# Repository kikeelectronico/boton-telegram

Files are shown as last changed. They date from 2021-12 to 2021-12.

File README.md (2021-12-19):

# El botón de Telegram
Se trata de un botón que envia un mesaje a través de Telegram hasta a cuatro usuarios.

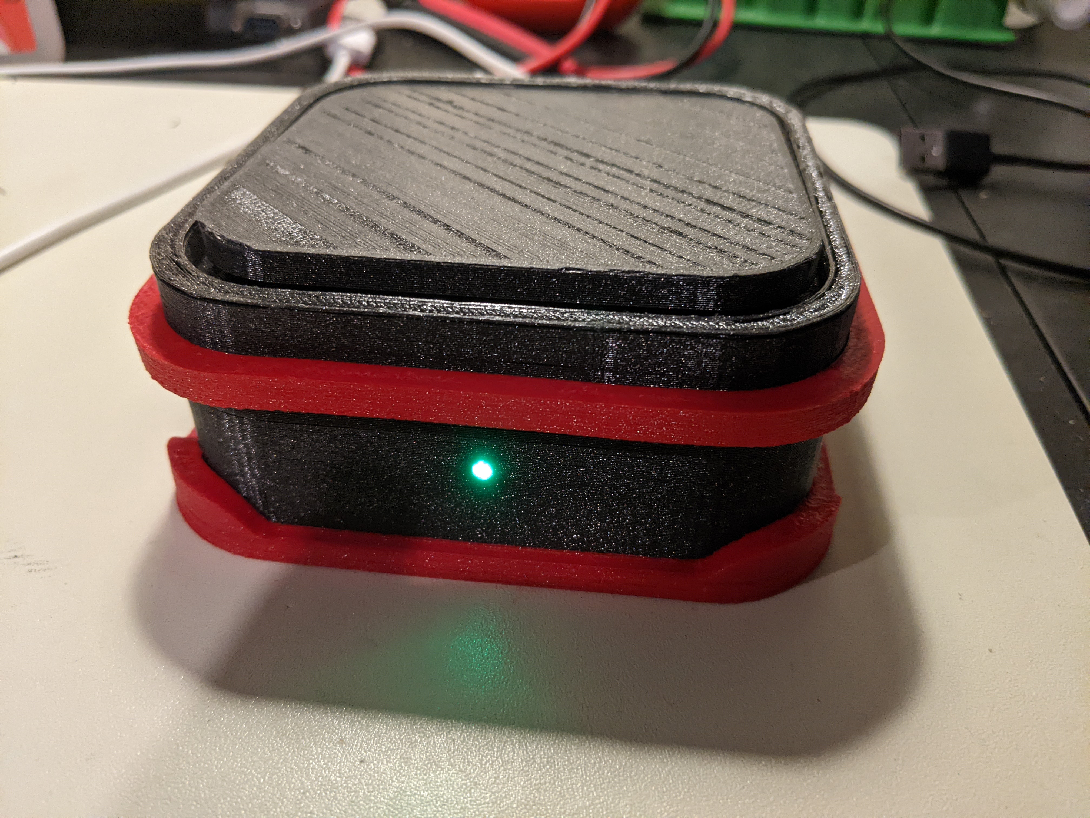
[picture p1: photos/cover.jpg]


# Materiales

- WeMos D1 mini
- Final de carrera.
- WS2812B LED
- PLA o material similar
- 2 tuercas M3
- 2 tornillos 45xM3
- Cable unifilar
- Tubo termoretráctil

# Herramientas

- PC
- Arduino IDE
- Soldador
- Impresora 3D

# Construcción

1. Imprime los modelos 3D de la caja.
2. Coloca el final de carrera usando los pines horizontales del centro de la pieza llamada Base.
3. Pega el LED detrás del agujero frontal de la base.
4. Coloca la placa WeMos D1 mini en el espacio reservado en el interior de la base.
5. Conecta el LED a Vcc, GND y al pin digital D6.
6. Conecta el final de carrera a GND y al pin digital D7.
7. Programa la placa usando el firmware y el IDE de Arduino.
8. Inserta 2 tuercas de métrica 3 en los huecos hexagonales de la pieza llamada Tapa.
9. Encaja la pieza llamada Botón en la pieza Tapa a través los agujeros redondos.
10. Encaja la Tapa en la Base y cierrala con dos tornillos de métrica 3 y 45 mm de largo desde la parte inferior.
11. Coloca las piezas decorativas: antideslizante y anillo.

# Conectar a tu red WiFi y configura el mensaje

Para realizar la configuración, El botón de Telegram genera su propia página web y red WiFi temporal a la que solo puedes acceder al estar cerca del dispositivo.

Para configurar botón:

1. Presiona el botón y no lo sueltes.
2. Conecta el cable USB.
3. Espera a que el LED se encienda en color amarillo.
4. Suelta el botón.

El botón de Telegram ha creado una red WiFi temporal llamada _Soy tu botón_ cuya contraseña es _vamosaconfigurarcosas_.

5. Conecta tu ordenador o dispositivo móvil a la red WiFi del botón.

Puede que el ordenador o el dispositivo móvil detecten que la red WiFi no tiene conexión a Internet. Si es así, el dispositivo pregunta si quieres mantener la conexión: mantenla.

6. Abre un navegador web y accede a la dirección http://192.168.4.1.
7. Rellena los datos de tu red WiFi, el token de tu bot de Telegram y el mensaje a enviar.

# Vincular una cuenta de Telegram para recibir mensajes

El botón puede enviar el mensaje hasta a cuatro usuarios de Telegram. Estos usuarios deben estar vinculados, un proceso que solo puedes llevar a cabo teniendo acceso físico al botón.

Para vincular un usuario:

1. Buscar tu bot en Telegram.
2. Inicia una conversación con el bot.
3. Envía el comando /start al bot y espera su respuesta.
4. Envía el comando /vincular y espera a que el LED del botón cambie al color morado.
5. Pulsa el botón.

Si el proceso de vinculación es correcto, el LED parpadea en color verde dos veces y el usuario recibe un mensaje del bot confirmando el proceso.

Si el proceso de vinculación falla, el LED parpadea en color rojo varias veces y el usuario recibe un mensaje del bot informando de que el proceso ha ido mal.

# El LED de colores

El botón de Telegram dispone de un LED con el que indica su estado.

|  Color |  Significado |
|---|---|
| Azul, fijo  | El dispositivo se está iniciando.  |
| Azul, parpadeo  | El dispositivo está buscando la red WiFi.  |
| Amarillo, fijo  | El dispositivo se encuentra en modo de configuración.  |
| Verde, parpadeo  | El proceso ha sido un éxito.  |
| Rojo, parpadeo  | El proceso ha fallado.  |
| Verde, fijo  | El dispositivo está preparado para enviar mensajes.  |

# Licencia
Creative Commons Atribución-CompartirIgual 4.0 Internacional.

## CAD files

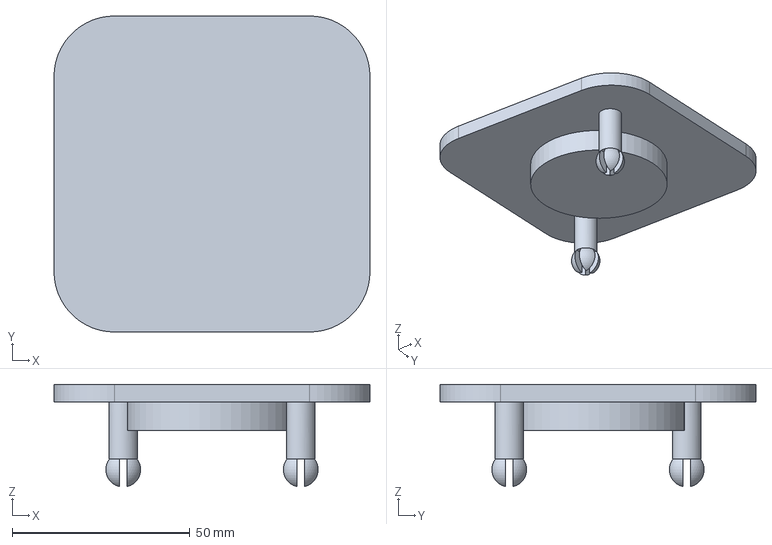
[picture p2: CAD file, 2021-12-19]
3D/botón.FCStd
89.0 x 89.0 x 28.8 mm

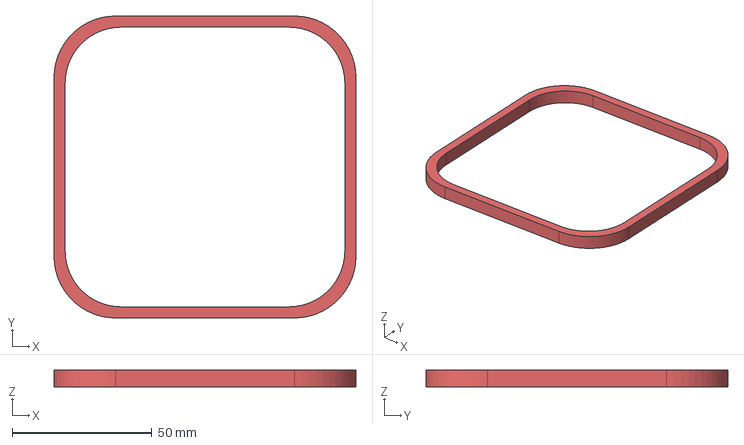
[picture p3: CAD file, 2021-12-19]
3D/anillo.FCStd
108.0 x 108.0 x 6.00 mm

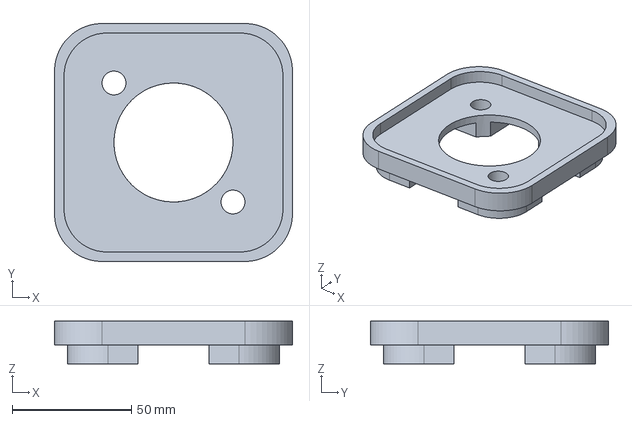
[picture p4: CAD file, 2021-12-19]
3D/tapa.FCStd
100.0 x 100.0 x 18.0 mm

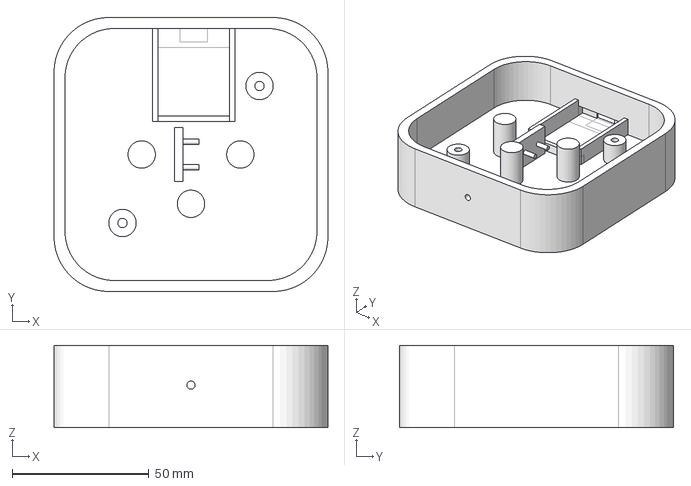
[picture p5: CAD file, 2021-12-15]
3D/base.FCStd
100.0 x 100.0 x 30.0 mm

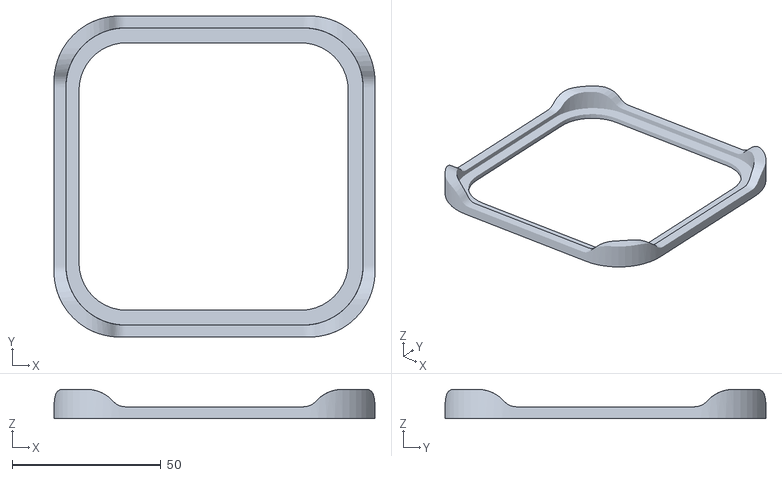
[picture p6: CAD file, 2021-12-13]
3D/antideslizante.stl
108.0 x 108.0 x 9.86

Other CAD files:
3D/anillo.stl
3D/base.stl
3D/botón.stl
3D/tapa.stl

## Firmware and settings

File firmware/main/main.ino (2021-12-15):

#include <ESP8266WiFi.h>
#include <EEPROM.h>
#include <WiFiClientSecure.h>
#include <UniversalTelegramBot.h>
#include <ESP8266WebServer.h>
#include <Adafruit_NeoPixel.h>
#include "constants.h"
#include "struct.h"
#include <stdio.h>
#include <string.h>

// Instances
X509List cert(TELEGRAM_CERTIFICATE_ROOT);
WiFiClientSecure client;
UniversalTelegramBot bot("", client);
Adafruit_NeoPixel pixels = Adafruit_NeoPixel(1, LED_PIN, NEO_GRB + NEO_KHZ800);
ESP8266WebServer server(80);

// Operational variables
configuration config;
volatile bool push_button_flag = false;
unsigned long start_wifi_time;
unsigned long start_link_time;
unsigned long last_bot_pool;
bool ap_mode = false;

ICACHE_RAM_ATTR void pushButtonInterrupt() {
  push_button_flag = true;
}

// Web server handlers
void handleRoot() {
  server.send(200, "text/html", SETTINGS_HOME_PAGE_1 + String(config.ssid)
                              + SETTINGS_HOME_PAGE_2 + String(config.password)
                              + SETTINGS_HOME_PAGE_3 + String(config.bot_token)
                              + SETTINGS_HOME_PAGE_4 + String(config.message)
                              + SETTINGS_HOME_PAGE_5);
}

void handleSave() {
  if (server.argName(0) == "ssid"
      && server.argName(1) == "password"
      && server.argName(2) == "bot_token"
      && server.argName(3) == "message") {
    // Save the settings
    server.arg(0).toCharArray(config.ssid, 50);
    server.arg(1).toCharArray(config.password, 50);
    server.arg(2).toCharArray(config.bot_token, 50);
    server.arg(3).toCharArray(config.message, 50);
    // Update the eeprom memory
    EEPROM.put(0,config);
    EEPROM.commit();
    server.send(200, "text/html", SETTINGS_SAVED_SUCCESS_1 + server.arg(0) + SETTINGS_SAVED_SUCCESS_2);
    for(uint8_t i = 0; i < 2; i++) {
      led(0,255,0);
      delay(200);
      led(255,255,0);
      delay(200);
    }
  } else {
    server.send(200, "text/html", SETTINGS_SAVED_FAIL);
    for(uint8_t i = 0; i < 5; i++) {
      led(255,0,0);
      delay(200);
      led(255,255,0);
      delay(200);
    }
  }
  
}

// Save a new chat id
bool setChatId(String new_id) {
  bool saved = false;
  // Save into the config var
  if(String(config.chat_id_a) == "") {
    new_id.toCharArray(config.chat_id_a, 50);
    saved = true;
  } else if(String(config.chat_id_b) == "") {
    new_id.toCharArray(config.chat_id_b, 50);
    saved = true;
  } else if(String(config.chat_id_c) == "") {
    new_id.toCharArray(config.chat_id_c, 50);
    saved = true;
  } else if(String(config.chat_id_d) == "") {
    new_id.toCharArray(config.chat_id_d, 50);
    saved = true;
  }
  // Update the eeprom memory
  EEPROM.put(0,config);
  EEPROM.commit();
  return saved;
}

// Telegram handler
void analyzeCommand(int numNewMessages) {
  for (int i=0; i<numNewMessages; i++) {    
    String text = bot.messages[i].text;
    String chat_id = String(bot.messages[i].chat_id);
    if (text == "/start") {
      bot.sendMessage(chat_id, START_MESSAGE, "");
    }
    if (text == "/vincular") {
      bot.sendMessage(chat_id, LINK_MESSAGE, "");
      led(255,0,255);
      start_link_time = millis();
      while (millis() - start_link_time < LINK_TIMEOUT && !push_button_flag) {
        delay(100);
      }

      if (push_button_flag) {
        if (setChatId(chat_id)) {
          String from_name = bot.messages[i].from_name;
          for(uint8_t i = 0; i < 2; i++) {
            led(0,255,0);
            delay(200);
            led(255,0,255);
            delay(200);
          }
          //bot.sendMessage(config.chat_id_a, LINK_SUCCESS_ADMIN_MESSAGE + from_name, "");
          bot.sendMessage(chat_id, LINK_SUCCESS_MESSAGE, "");   
        } else {
          for(uint8_t i = 0; i < 5; i++) {
            led(255,0,0);
            delay(200);
            led(255,0,255);
            delay(200);
          }
          bot.sendMessage(chat_id, LINK_FAIL_MESSAGE, "");
        }        
      } else {
        for(uint8_t i = 0; i < 5; i++) {
          led(255,0,0);
          delay(200);
          led(255,0,255);
          delay(200);
        }
        bot.sendMessage(chat_id, LINK_FAIL_MESSAGE, "");
      }
      push_button_flag = false;
      led(0,255,0); 
    }

  }
}

void led(uint8_t r, uint8_t g, uint8_t b) {
  uint32_t color = pixels.Color(r,g,b);
  pixels.setPixelColor(0, color);
  pixels.show();
}

// Enable AP mode
void enableApMode() {
  Serial.println("Creating an AP");
  WiFi.softAP(AP_NAME, AP_PASSWORD);
  Serial.println("Booting the congif server");
  server.on("/", handleRoot);
  server.on("/save", handleSave);
  server.begin();
  push_button_flag = false;
  led(255,255,0);
}

void setup() {
  // Set comms
  Serial.begin(115200);
  // Begin the LED
  pixels.begin();
  // Welcome
  Serial.println("\nHi. I am your button.");
  for (uint8_t i = 0; i < 200; i+=10) {
    led(0,0,i);
    delay(100);
  }
  led(0,0,0);
  // Set IO
  pinMode(PUSH_BUTTON_PIN, INPUT_PULLUP);
  attachInterrupt(digitalPinToInterrupt(PUSH_BUTTON_PIN), pushButtonInterrupt, RISING);
  if (!digitalRead(PUSH_BUTTON_PIN)) {
    ap_mode = true;
    Serial.println("AP mode enabled");
  }
  // Get the config data from eeprom
  EEPROM.begin(512);
  delay(100);
  EEPROM.get(0, config);
  // Set the Telegram token
  bot.updateToken(config.bot_token);
  // Config UTC time
  configTime(0, 0, "pool.ntp.org");
  // Config the trust certs
  client.setTrustAnchors(&cert);
  if (!ap_mode) {
    // Connect to the network
    Serial.println("Connecting to WiFi");
    WiFi.mode(WIFI_STA);
    WiFi.begin(config.ssid, config.password);
    start_wifi_time = millis();
    while (WiFi.status() != WL_CONNECTED && millis() - start_wifi_time < WIFI_TIMEOUT) {
      Serial.print(".");
      led(0,0,255);
      delay(500);
      led(0,0,0);
      delay(500);
    }
    if (WiFi.status() != WL_CONNECTED) {
      for(uint8_t i = 0; i < 5; i++) {
        led(0,0,255);
        delay(200);
        led(255,0,0);
        delay(200);
      }
      led(0,0,0);
      enableApMode();
    } else {
      led(0,255,0);
    }
  } else {
    enableApMode();
  }
  
}

void loop() {
  // Pool the bot every BOT_POOL_DELAY miliseconds
  if (millis() - last_bot_pool > BOT_POOL_DELAY)  {
    int buffer_size = bot.getUpdates(bot.last_message_received + 1);
    // Clear the buffer of messages
    while (buffer_size) {
      analyzeCommand(buffer_size);
      buffer_size = bot.getUpdates(bot.last_message_received + 1);
    }
    last_bot_pool = millis();
  }
  // Handle web clients
  if (ap_mode) {
    server.handleClient();
  }
  // Send the message
  if (!ap_mode && push_button_flag) {
    push_button_flag = false;
    for(uint8_t i = 0; i < 2; i++) {
      led(0,0,0);
      delay(200);
      led(0,255,0);
      delay(200);
    }
    if (strlen(config.chat_id_a) > 2)
      bot.sendMessage(config.chat_id_a, config.message, "");
    if (strlen(config.chat_id_b) > 2)
      bot.sendMessage(config.chat_id_b, config.message, "");
    if (strlen(config.chat_id_c) > 2)
      bot.sendMessage(config.chat_id_c, config.message, "");
    if (strlen(config.chat_id_d) > 2)
      bot.sendMessage(config.chat_id_d, config.message, "");
  }
}

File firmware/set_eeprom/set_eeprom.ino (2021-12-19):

/*
  This code allows you to configure the button manually.
  1. Type your configuration in my_configuration variable.
  2. Load the program in the board.
  3. Load the firmware in the board.
*/

#include <EEPROM.h>

struct configuration {
  char ssid[50];
  char password[50];
  char bot_token[50];
  char message[50];
  char chat_id_a[50];
  char chat_id_b[50];
  char chat_id_c[50];
  char chat_id_d[50];
};

configuration my_configuration = {
  "",
  "",
  "",
  "",
  "",
  "",
  "",
  "",
};

configuration my_configuration_readed;

void setup() {  
  
  Serial.begin(115200);   
  
  EEPROM.begin(512);
  delay(100);
  EEPROM.put(0,my_configuration);
  EEPROM.commit();
  
  EEPROM.get(0, my_configuration_readed);
  Serial.println("");
  Serial.println("");
  Serial.println(my_configuration_readed.ssid);
  Serial.println(my_configuration_readed.password);
  Serial.println(my_configuration_readed.bot_token);
  Serial.println(my_configuration_readed.message);
  Serial.println(my_configuration_readed.chat_id_a);
  Serial.println(my_configuration_readed.chat_id_b);
  Serial.println(my_configuration_readed.chat_id_c);
  Serial.println(my_configuration_readed.chat_id_d);
  Serial.println("");

}

void loop() {

}

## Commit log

2021-12-13 3D design
    [antideslizante.FCStd, antideslizante.stl, base.FCStd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]
2021-12-14 Push button ISR and link telegram account
2021-12-14 ap mode if wifi fails
    [main.ino]
2021-12-15 LED for notifications and status
2021-12-15 changes at 3D
    [base.FCStd, base.stl, tapa.FCStd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]
2021-12-19 more 3d design
    [anillo.FCStd, anillo.stl, tapa.FCStd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]
2021-12-19 botón 3D
    [botón.FCStd, botón.stl]
